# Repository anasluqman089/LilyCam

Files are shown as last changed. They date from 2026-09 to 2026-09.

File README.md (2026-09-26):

# LilyCam



LilyCam is a custom DIY digital camera built from scratch around the Seeed Studio XIAO ESP32-S3 Sense, a tiny, low-cost microcontroller board with an integrated camera sensor and microSD card slot inspired by the Kodak Charmera Keychain

The idea behind the name

"Lily" evokes something small, elegant, and blooming. A compact camera that fits in your palm but still delivers personality through its built-in creative filters making photography playful and personal.

## What it does
Core Features :

Button	Function

SW1 — Power	Toggles the camera between active mode and deep sleep (ultra-low battery drain)

SW2 — Shutter	Captures a photo and saves it to the microSD card

SW3 — Style	Cycles creative color filters: Normal → Grayscale → Negative → Sepia → Night Vision Green

## BOM

| Item | Qty | Part Name | Description | Price (\$) | Product Page Link |
| :---: | :---: | :--- | :--- | :---: | :--- |
| **1** | 1 | Seeed Studio XIAO ESP32-S3 Sense | Dual-core ESP32-S3 MCU with detachable OV2640 camera board and digital mic | \$13.90 | [Seeed Studio Product Page](https://www.seeedstudio.com/XIAO-ESP32S3-Sense-p-5639.html) |
| **2** | 3 | 6mm Tactile Switch (6x6x5mm) | 4-pin momentary push button for hardware input/reset | \$1.00 | Search target: `6x6x5mm tactile switch pack` |
| **3** | 1 | 1.3 Inch TFT IPS Display Module | 240x240 Full-Color Screen with SPI interface (ST7789 Driver) | \$7.99 | [Amazon Product Page](https://www.amazon.com/Display-Module-240x240-Interface-Arduino/dp/B0DN9NMBFW/ref=sr_1_10) |

### Note
* **PCB and 3D printing**: PCB and 3D printind doesnt included in the Bill of material. 
* **Buttons (Tactile Switches)**: These are universally sold in multi-packs (usually 10 to 50 pieces) rather than single units, which accounts for the \$1.00 baseline package price. 
* **Display Interface**: The 1.3-inch screen utilizes a **4-wire SPI communication interface** driven by the **ST7789** controller chip. Ensure you match the pinout labels (GND, VCC, SCL, SDA, RES, DC, BLK) to the corresponding digital pins on your XIAO module during assembly.

## Schematics



## PCB


## CAD







## Extra
This project is made for Hack Club YSWS program : Stardance
Links : https://stardance.hackclub.com/projects/59421

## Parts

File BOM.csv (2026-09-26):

Item | Qty | Part Name | Description | Price ($) | Product Page Link
1 | 1 | Seeed Studio XIAO ESP32-S3 Sense | Main MCU | 13.90 | https://www.seeedstudio.com/XIAO-ESP32S3-Sense-p-5639.html
2 | 3 | 6mm Tactile Switch (6x6x5mm) | 4-pin momentary push button for hardware input/reset | $1.00 | (Cant find link that sells 3 button)
3 | 1 | 1.3 Inch TFT IPS Display Module | 240x240 Full-Color Screen with SPI interface (ST7789 Driver) | $7.99 | https://www.amazon.com/Display-Module-240x240-Interface-Arduino/dp/B0DN9NMBFW/ref=sr_1_10

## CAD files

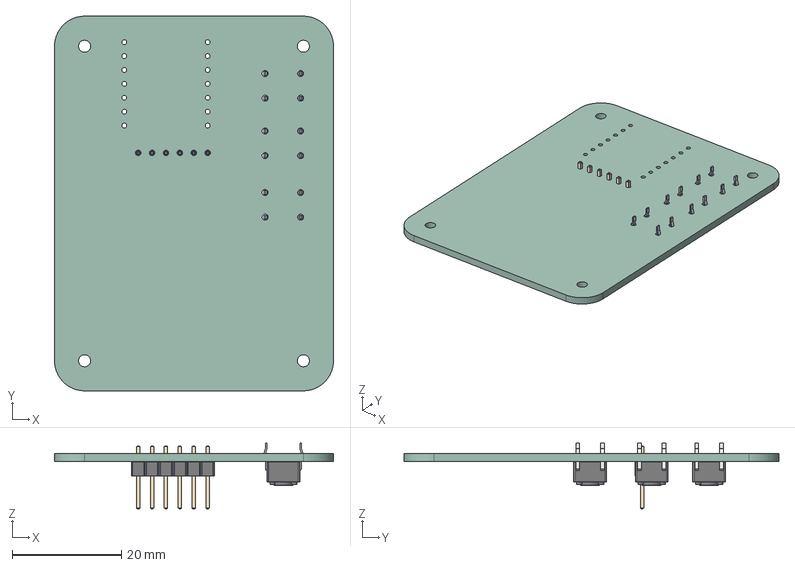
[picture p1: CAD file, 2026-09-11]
CAD/LilyCam CAD.step
51.0 x 68.5 x 12.0 mm
SW_PUSH_6mm x 3
PinHeader_1x06_P254mm_Vertical
LilyCam_PCB

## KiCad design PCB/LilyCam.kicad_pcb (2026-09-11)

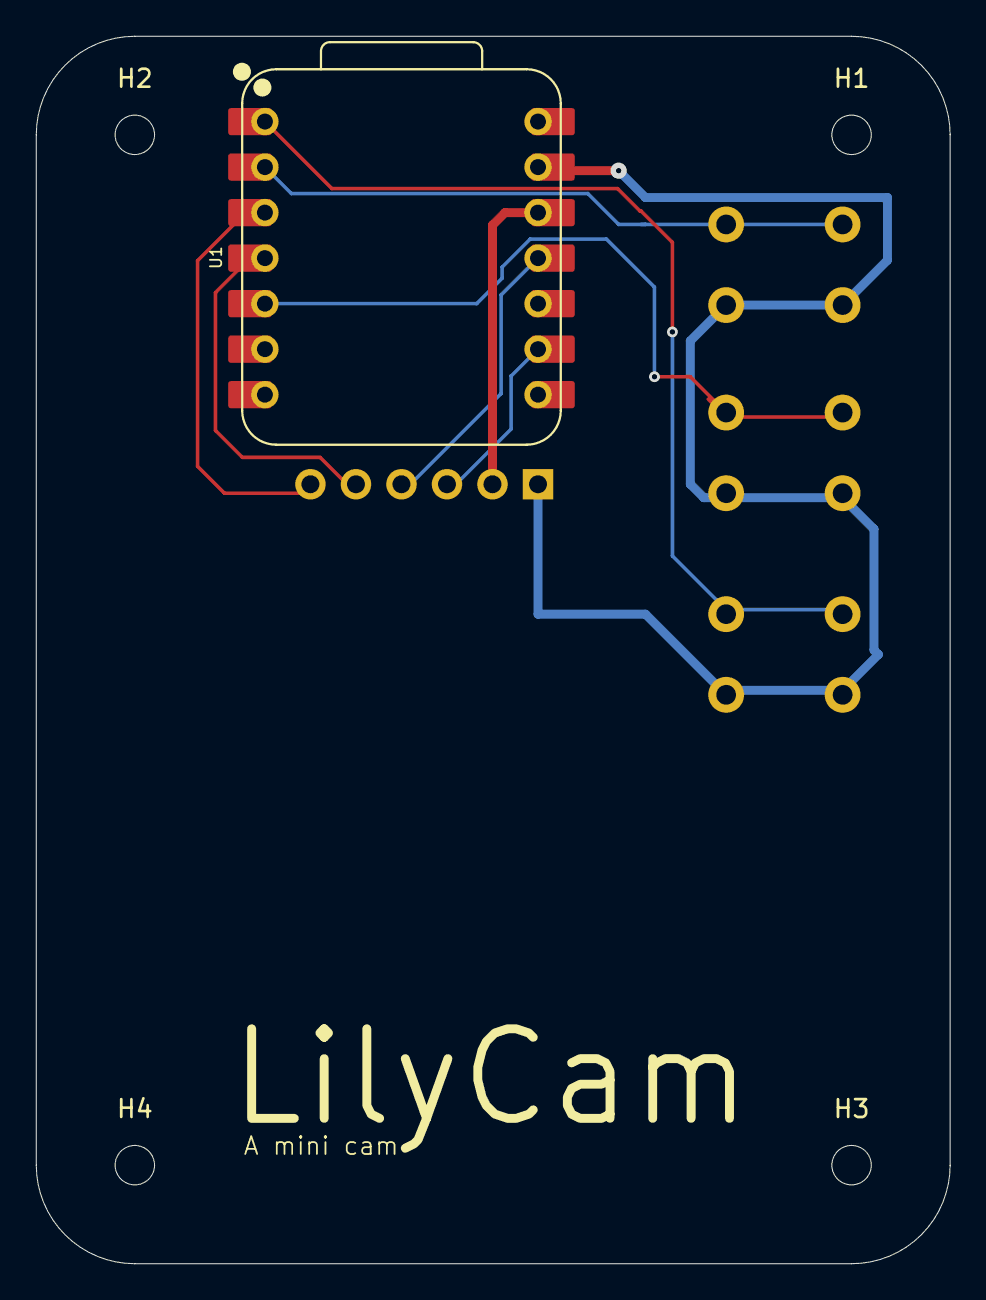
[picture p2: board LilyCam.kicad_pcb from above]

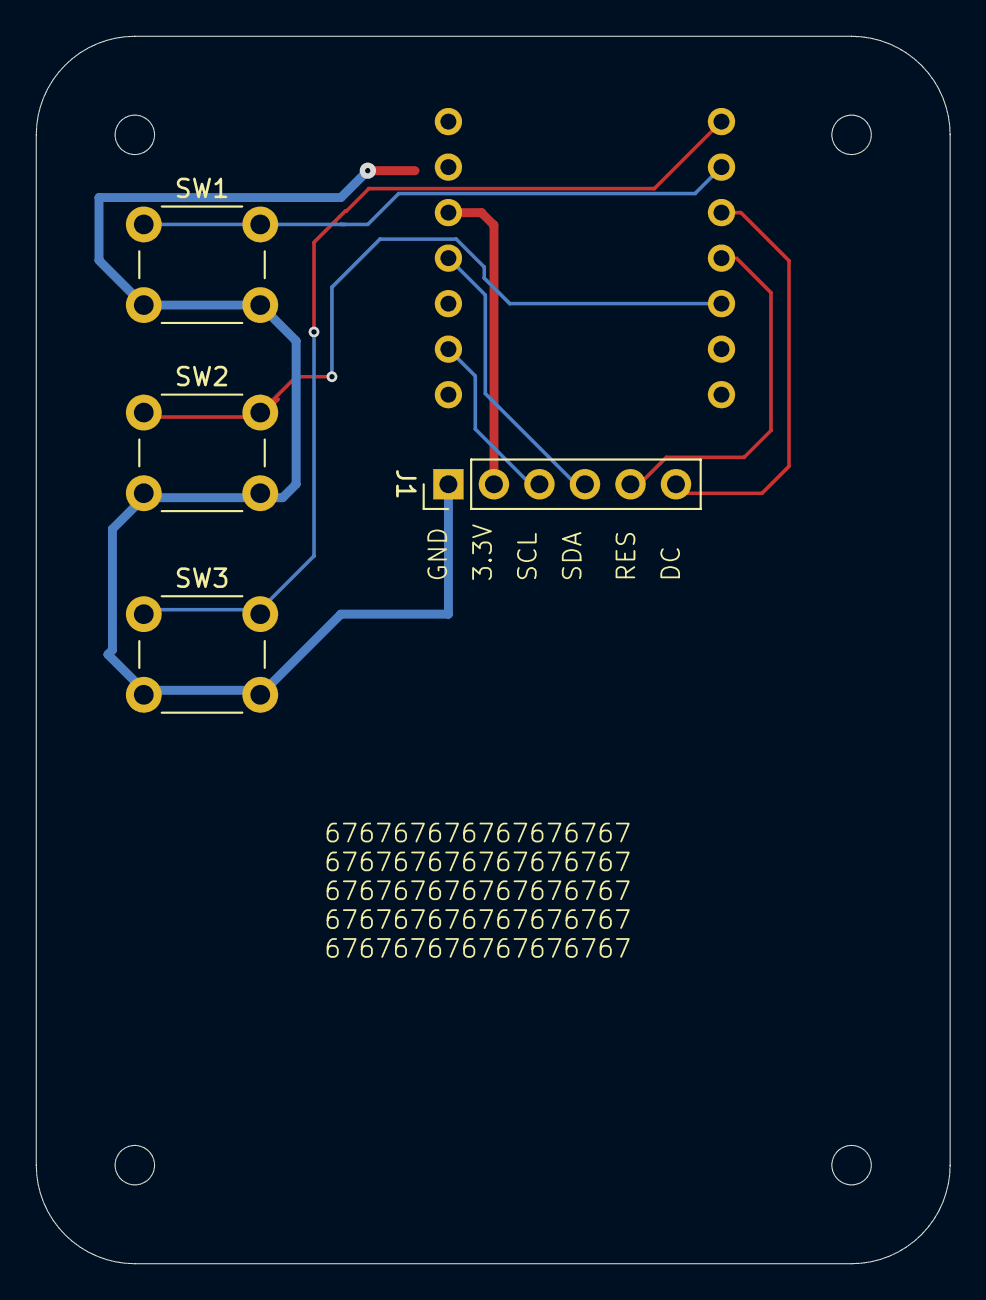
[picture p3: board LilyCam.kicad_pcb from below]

Board: 2 copper layers, 51.0 x 68.5 mm, 9 parts (4 on the bottom side), 9 nets.

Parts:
H1, H2, H3, H4: MountingHole; MountingHole_2.2mm_M2
J1: Conn_01x06_Socket; PinHeader_1x06_P2.54mm_Vertical
SW1, SW2, SW3: SW_Push; SW_PUSH_6mm
U1: XIAO-ESP32-S3-SMD; XIAO-ESP32-S3-DIP

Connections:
+3.3V: J1.2, U1.12 (3V3_OUT)
/1: SW3.1, U1.1 (D0)
/2: SW1.1, U1.2 (D1)
/3: SW2.1, U1.5 (D4)
/DC: J1.6, U1.3 (D2)
/RES: J1.5, U1.4 (D3)
/SCL: J1.3, U1.9 (D8)
/SDA: J1.4, U1.11 (D10)
GND: J1.1, SW1.2, SW2.2, SW3.2, U1.13 (GND)

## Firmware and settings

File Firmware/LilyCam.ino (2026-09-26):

// DIY Camera — Seeed XIAO ESP32-S3 Sense + 1.3" ST7735 TFT
// SW1 (GPIO1) = Sleep/Wake   
// SW2 (GPIO2) = Shutter
// SW3 (GPIO6) = Filter cycle
#include "esp_camera.h"
#include "SD.h"
#include "SPI.h"
#include "Arduino_GFX_Library.h"
#include "driver/rtc_io.h"

//Pin map (XIAO ESP32-S3)
#define BTN_SLEEP   1  
#define BTN_SHUTTER 2 
#define BTN_FILTER  6  

// Display (SPI)
#define TFT_CS    21   
#define TFT_SCLK  43   
#define TFT_MOSI  44  
#define TFT_RST   4 
#define TFT_DC    5   
#define SD_CS     21    

// Camera pins (Sense board)
#define PWDN -1
#define RESET -1
#define XCLK  10
#define SIOD  40
#define SIOC  39
#define Y9    48
#define Y8    11
#define Y7    12
#define Y6    14
#define Y5    16
#define Y4    18
#define Y3    17
#define Y2    15
#define VSYNC 38
#define HREF  47
#define PCLK  13

// Display
Arduino_GFX *gfx = new Arduino_ST7735(
    TFT_CS /*or -1 if CS tied to GND*/, TFT_DC, TFT_RST,
    SPI_MODE2, 160, 128, TFT_SCLK, TFT_MOSI);

// State
enum Filter { NORMAL, GRAYSCALE, NEGATIVE, SEPIA, NIGHTGREEN };
const char* filterNames[] = {"NORMAL","GRAY","NEGATIVE","SEPIA","NIGHT"};
int filter = NORMAL;
bool sleeping = false;
uint16_t frameBuf[160 * 128];

void startCamera() {
  camera_config_t cfg;
  cfg.ledc_channel = LEDC_CHANNEL_0;
  cfg.ledc_timer   = LEDC_TIMER_0;
  cfg.pin_d0 = Y2; cfg.pin_d1 = Y3; cfg.pin_d2 = Y4; cfg.pin_d3 = Y5;
  cfg.pin_d4 = Y6; cfg.pin_d5 = Y7; cfg.pin_d6 = Y8; cfg.pin_d7 = Y9;
  cfg.pin_xclk = XCLK; cfg.pin_pclk = PCLK;
  cfg.pin_vsync = VSYNC; cfg.pin_href = HREF;
  cfg.pin_sscb_sda = SIOD; cfg.pin_sscb_scl = SIOC;
  cfg.pin_pwdn = PWDN; cfg.pin_reset = RESET;
  cfg.xclk_freq_hz = 20000000;
  cfg.pixel_format = PIXFORMAT_RGB565;  
  cfg.frame_size   = FRAMESIZE_QQVGA;    
  cfg.fb_count = 1;
  cfg.grab_mode = CAMERA_GRAB_LATEST;
  esp_camera_init(&cfg);
}

void applyFilter(uint16_t &px) {
  int r = (px >> 11) & 0x1F, g = (px >> 5) & 0x3F, b = px & 0x1F;
  switch (filter) {
    case GRAYSCALE: {
      uint8_t y = (r*8 + g*10 + b*2) / 4;
      r = g = b = min(31, y >> 1); g = min(63, y); break;
    }
    case NEGATIVE: r = 31 - r; g = 63 - g; b = 31 - b; break;
    case SEPIA: {
      int rr = min(31,(r*13 + g*6)>>4), gg = min(63,(r*5 + g*10 + b*1)>>4);
      r = rr; g = gg; b = min(31, gg >> 2); break;
    }
    case NIGHTGREEN: g = 63 - g; r = 0; b = 0; break;
    default: return;
  }
  px = (r << 11) | (g << 5) | b;
}

void captureAndShow() {
  camera_fb_t *fb = esp_camera_fb_get();
  if (!fb) return;
  uint16_t *src = (uint16_t*)fb->buf;
  for (int y = 0; y < 120; y++)
    for (int x = 0; x < 160; x++) {
      uint16_t px = src[y * 160 + x];
      px = (px >> 8) | (px << 8);
      applyFilter(px);
      frameBuf[(y + 4) * 160 + x] = px;
    }
  esp_camera_fb_return(fb);
  gfx->draw16bitRGBBitmap(0, 0, frameBuf, 160, 128);
  // HUD
  gfx->setTextColor(RGB565_WHITE);
  gfx->setCursor(2, 2); gfx->print(filterNames[filter]);
}

bool saveToSD() {
  SD.begin(SD_CS);
  File f = SD.open("/shot.raw", FILE_WRITE);
  if (!f) return false;
  f.write((uint8_t*)frameBuf, sizeof(frameBuf));
  f.close();
  return true;
}

void goToSleep() {
  gfx->fillScreen(BLACK);
  esp_camera_deinit();
  esp_sleep_enable_ext0_wakeup(GPIO_NUM_1, 0); // SW1 press (LOW) wakes
  esp_deep_sleep_start();
}

void setup() {
  pinMode(BTN_SLEEP, INPUT_PULLUP);
  pinMode(BTN_SHUTTER, INPUT_PULLUP);
  pinMode(BTN_FILTER, INPUT_PULLUP);

  esp_sleep_enable_ext0_wakeup(GPIO_NUM_1, 0);
  if (esp_sleep_get_wakeup_cause() == ESP_SLEEP_WAKEUP_EXT0)
    filter = NORMAL; // woke up

  gfx->begin();
  gfx->fillScreen(BLACK);
  gfx->setTextColor(RGB565_WHITE);
  gfx->setCursor(20, 56); gfx->print("DIY CAM booting...");
  startCamera();
  captureAndShow();
}

void loop() {
  static uint32_t lastBtn = 0;
  if (millis() - lastBtn < 250) return;

  if (digitalRead(BTN_SLEEP) == LOW) {
    lastBtn = millis();
    goToSleep();
  }
  if (digitalRead(BTN_SHUTTER) == LOW) {
    lastBtn = millis();
    captureAndShow();
    if (saveToSD()) {
      gfx->fillRect(2, 118, 80, 10, BLACK);
      gfx->setCursor(2, 118); gfx->print("SAVED!");
    }
  }
  if (digitalRead(BTN_FILTER) == LOW) {
    lastBtn = millis();
    filter = (filter + 1) % 5;
    captureAndShow(); // re-show last view with new filter
  }
}

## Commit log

2026-09-11 Expand README with project details and images
    Added detailed project description, features, BOM, schematics, PCB, CAD images, and extra information about the project.
2026-09-11 Add BOM link to README
    Added a link to the BOM in the README.
2026-09-26 Updated the file
    [Hardware Bill of Materials.xlsx, LilyCam CAD.step, LilyCam PCB.step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]
2026-09-26 Revise BOM.csv with new prices and product links
    Updated prices and links for components in BOM.
    [BOM.csv]
2026-09-26 Add BOM section to README with item details
    Added BOM section with item details and notes.
2026-09-26 Update README with PCB and 3D printing note
    Added note about PCB and 3D printing not included in the Bill of Materials.
